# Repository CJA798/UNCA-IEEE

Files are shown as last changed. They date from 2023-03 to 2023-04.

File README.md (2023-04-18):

# UNCA-IEEE
### This repository contains all the latest code and CAD files for the bot
#### Important Links:
- [South East Con 2023 Hardware Competition](https://ieeesoutheastcon.org/)
- [Rules v3.0](https://ieeesoutheastcon.org/wp-content/uploads/sites/392/IEEE-SoutheastCon-2023-Hardware-Competition-Rules-v3.0.pdf)
- [Competition Schedule](https://ieeesoutheastcon.org/student-competitions/)

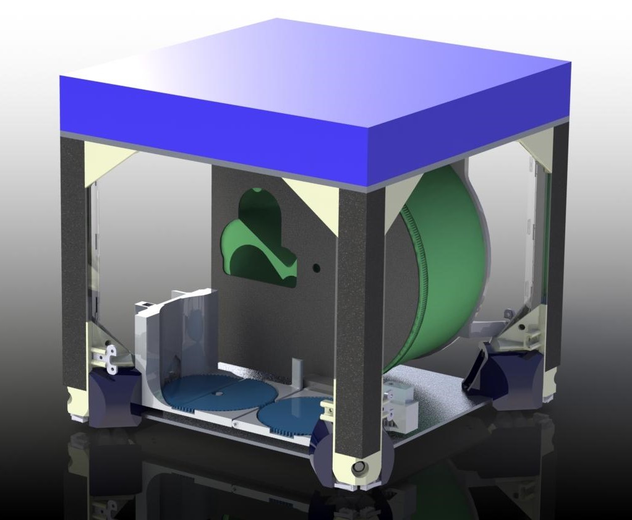
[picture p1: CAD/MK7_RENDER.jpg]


- <sub>[( ͡° ͜ʖ ͡°)](https://youtu.be/dQw4w9WgXcQ)</sub>

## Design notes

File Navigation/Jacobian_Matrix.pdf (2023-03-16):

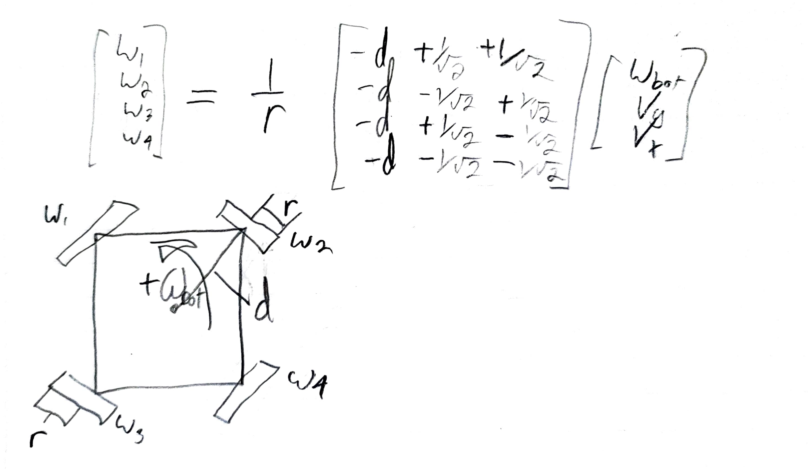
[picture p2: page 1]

-d t+
-V2 t
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
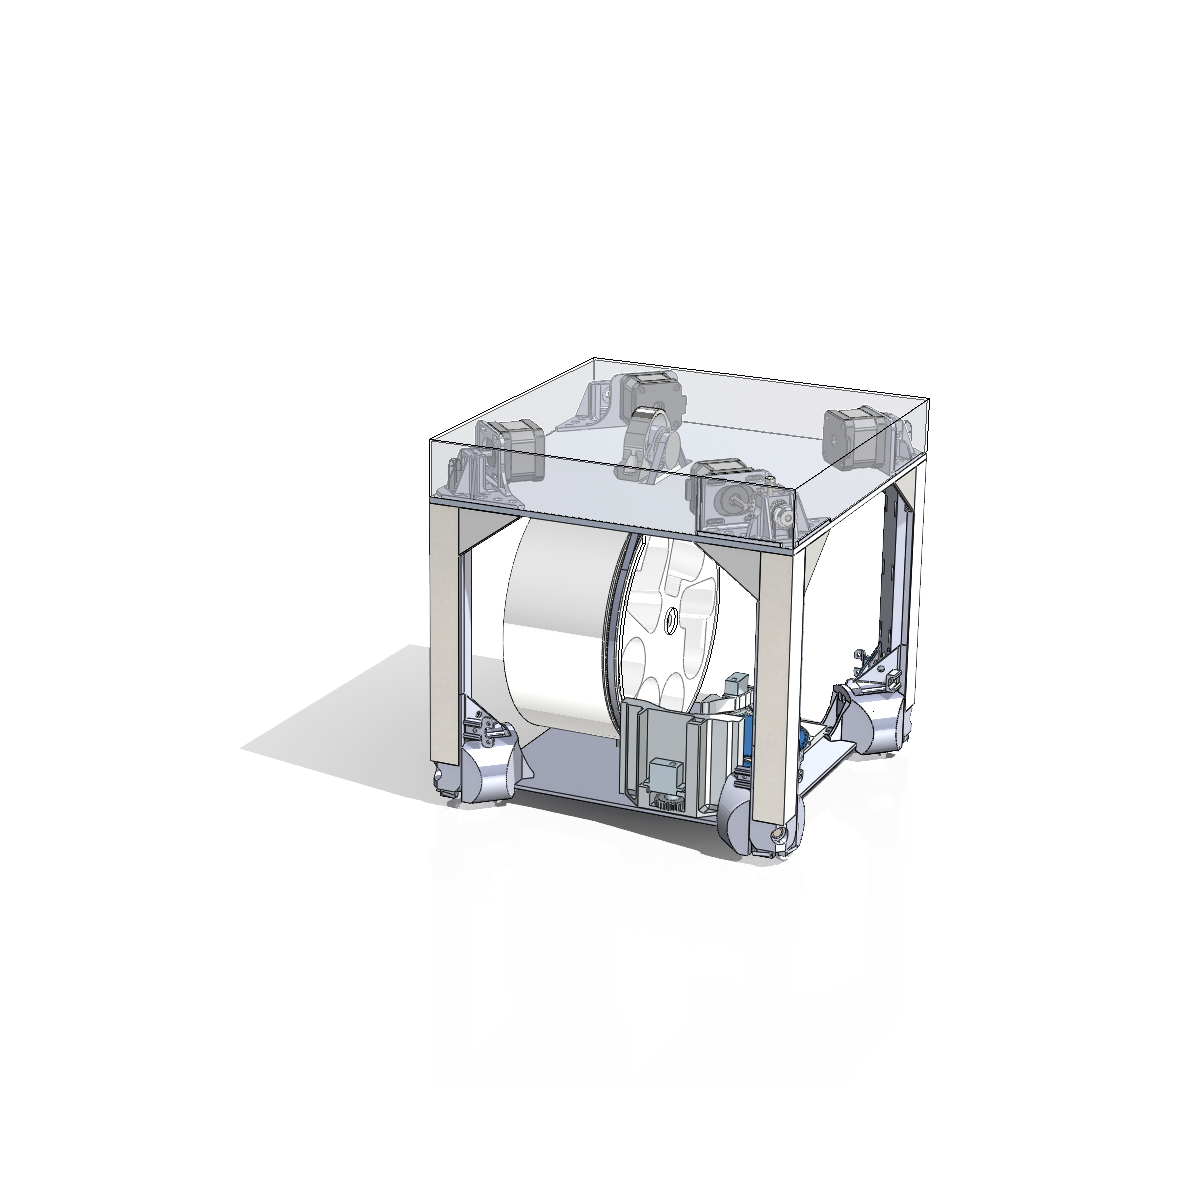
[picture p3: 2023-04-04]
CAD/MK5 IEEE BOT.PNG

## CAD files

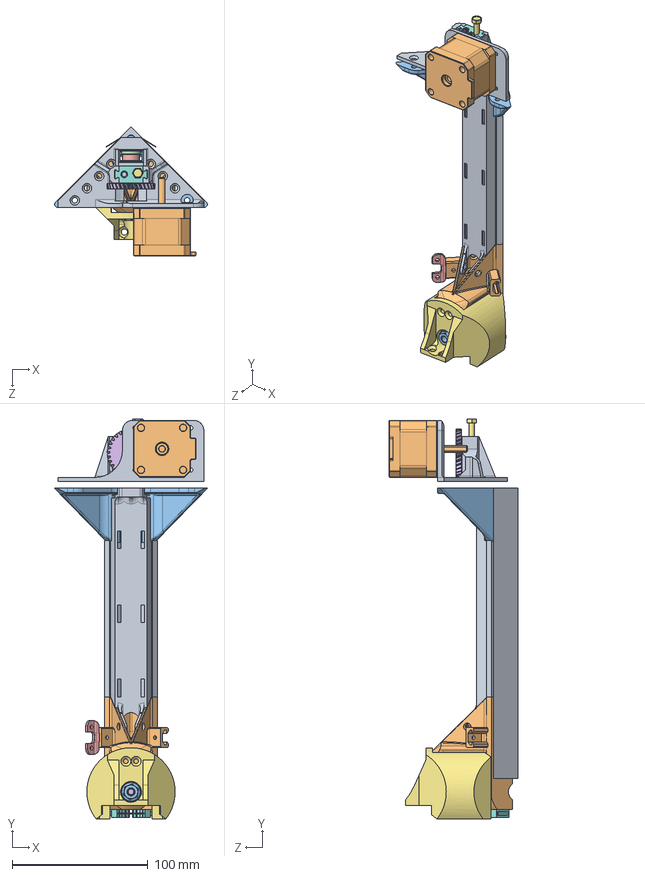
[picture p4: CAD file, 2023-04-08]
WORKING ASSEMBLY/MK7.1 IEEE BOT/LEG assem MK5.SLDASM
112.8 x 294.6 x 95.1 mm
Omniwheel Mount-MK5
Leg Bracket MK5
Omniwheel Hub
TOF sensor mount
Pinion Drive
Bottom Plate Bracket
Bearing Slider
Steel 90 degree MK5
Nema17.step
instrument ball bearing_68_am
6mm G2T Pully Gear
hex flange screw_am
Microswitch x 2
BeltShroud

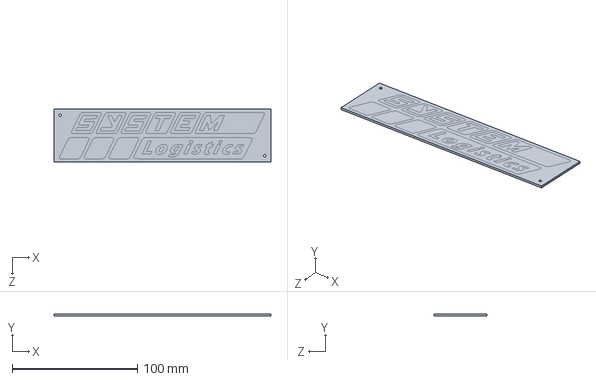
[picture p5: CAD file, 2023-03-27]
CAD/System Logistics Logo.SLDPRT
173.1 x 1.50 x 42.5 mm

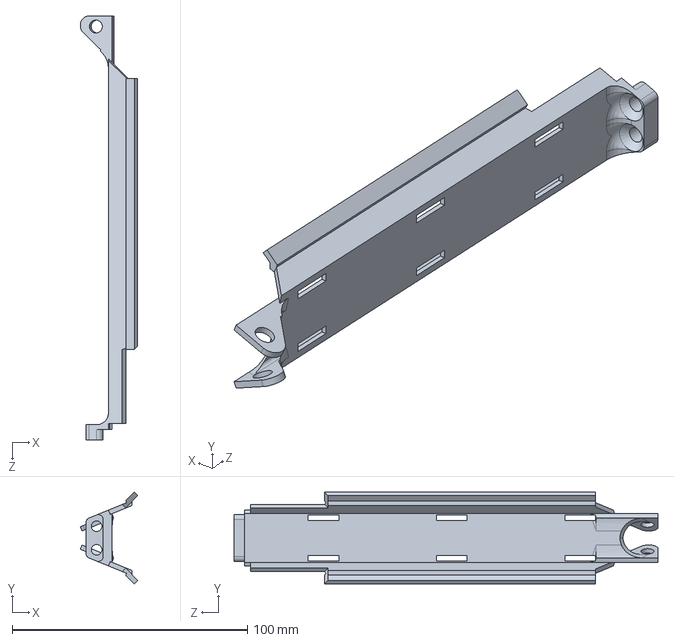
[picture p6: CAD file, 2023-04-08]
WORKING ASSEMBLY/MK7.1 IEEE BOT/BeltShroud.SLDPRT
24.4 x 39.0 x 180.1 mm

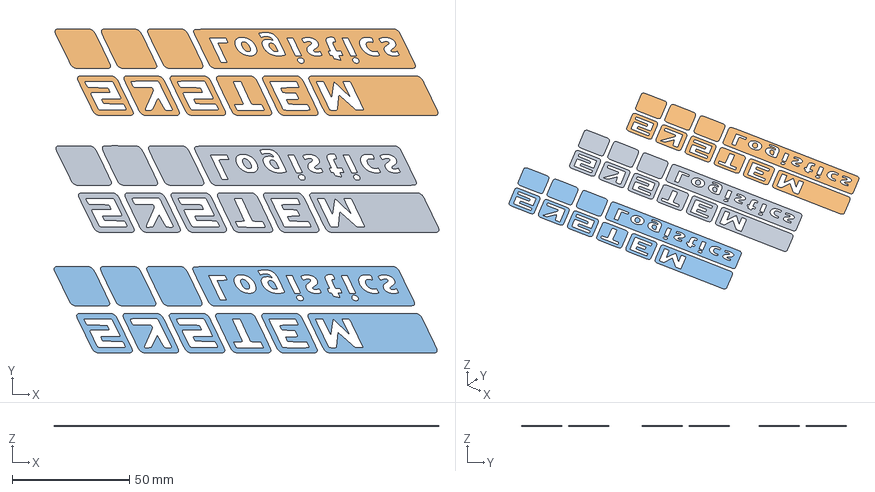
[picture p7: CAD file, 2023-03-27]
CAD/3 System Logistics Logos.3mf
164.3 x 138.4 x 0.18 mm
System Logistics Logo x 3

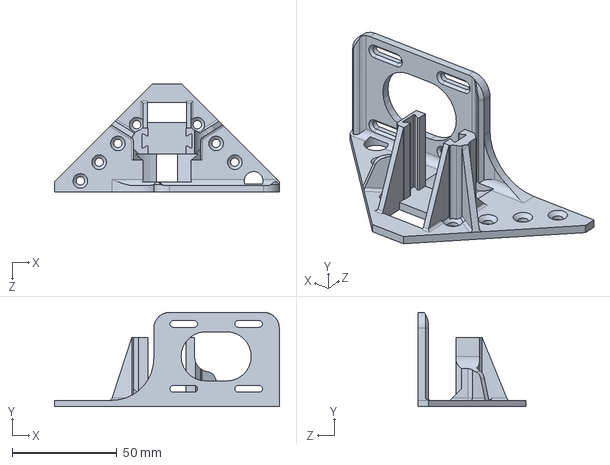
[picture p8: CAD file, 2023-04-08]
WORKING ASSEMBLY/MK7.1 IEEE BOT/Pinion Drive.SLDPRT
107.5 x 45.0 x 51.6 mm

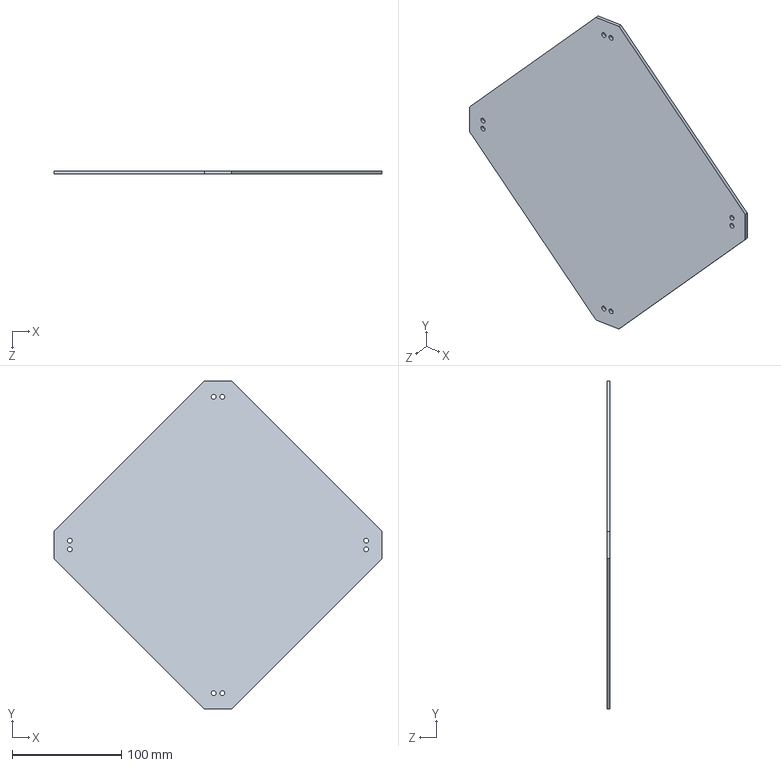
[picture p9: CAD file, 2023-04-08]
WORKING ASSEMBLY/MK7.1 IEEE BOT/Bottom Plate21.SLDPRT
300.7 x 300.7 x 3.00 mm

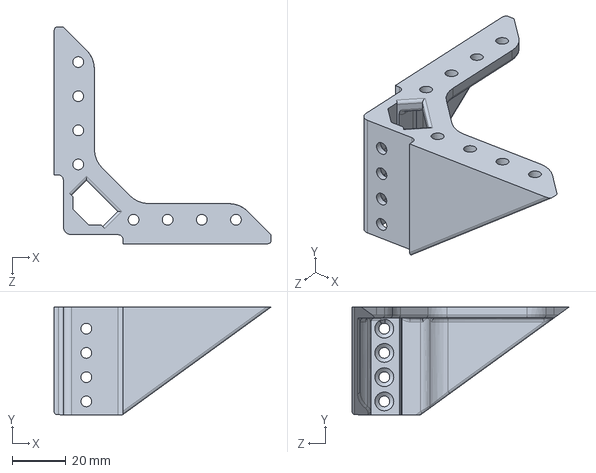
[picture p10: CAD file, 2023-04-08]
WORKING ASSEMBLY/MK7.1 IEEE BOT/Leg Bracket MK5.SLDPRT
80.5 x 40.0 x 80.5 mm

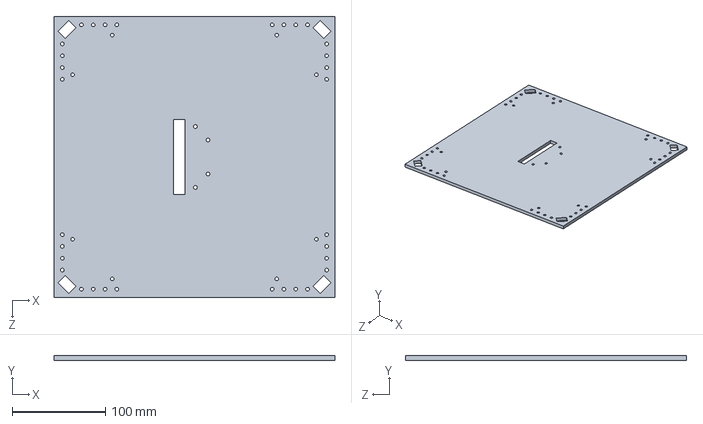
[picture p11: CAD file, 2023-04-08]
WORKING ASSEMBLY/MK7.1 IEEE BOT/MK5 Top Plate.SLDPRT
301.6 x 5.00 x 301.6 mm

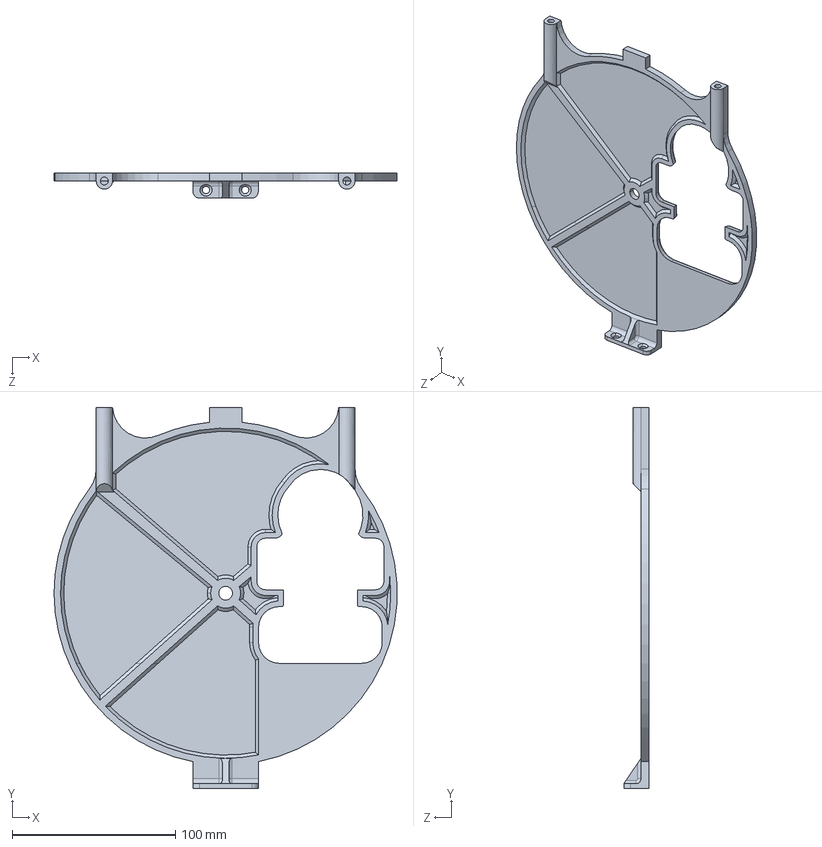
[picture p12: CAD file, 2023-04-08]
WORKING ASSEMBLY/MK7.1 IEEE BOT/DrumHolderBackPlate.step.SLDPRT
209.8 x 233.1 x 15.5 mm

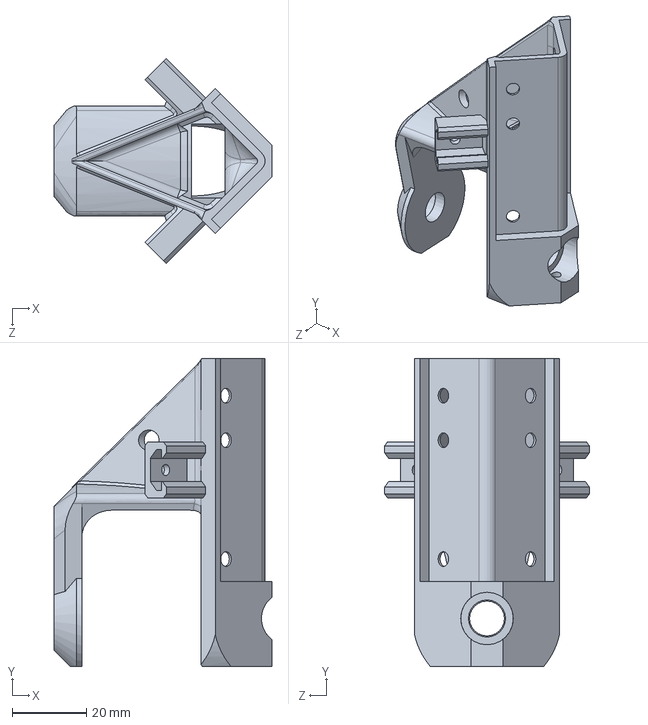
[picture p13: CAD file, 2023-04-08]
WORKING ASSEMBLY/MK7.1 IEEE BOT/Omniwheel Mount-MK5.SLDPRT
58.7 x 82.9 x 55.1 mm

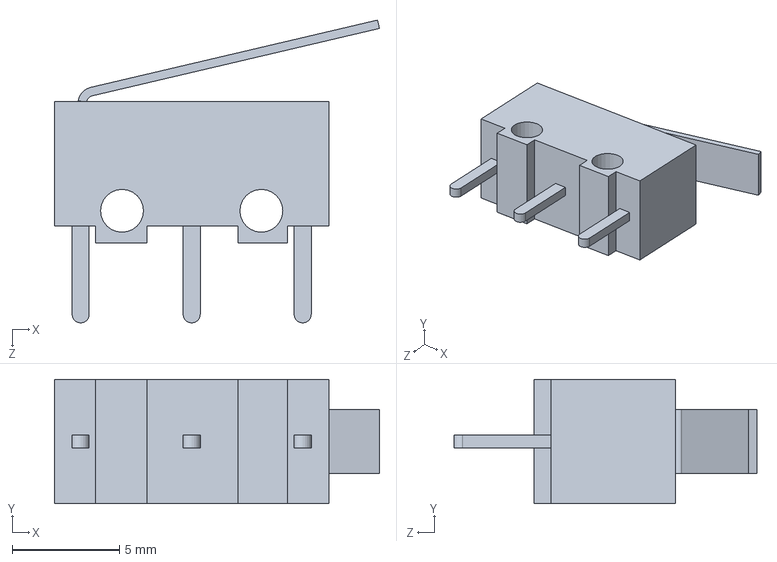
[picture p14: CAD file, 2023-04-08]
WORKING ASSEMBLY/MK7.1 IEEE BOT/Microswitch.SLDPRT
15.2 x 5.80 x 14.1 mm

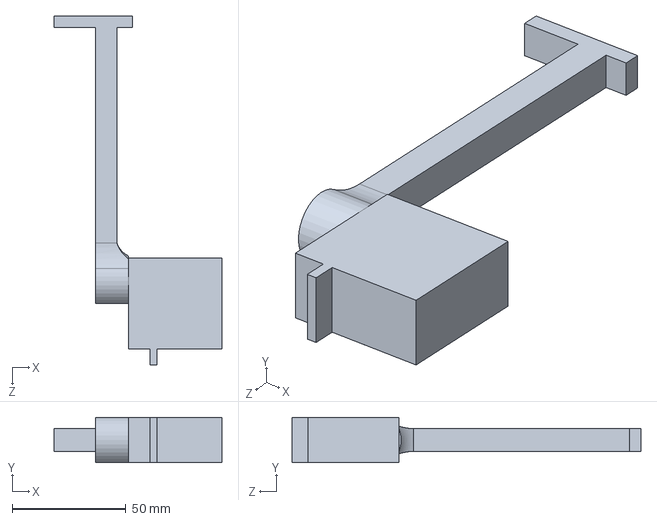
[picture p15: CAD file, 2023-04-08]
WORKING ASSEMBLY/MK7.1 IEEE BOT/DuckKicker.SLDPRT
73.7 x 20.0 x 153.6 mm

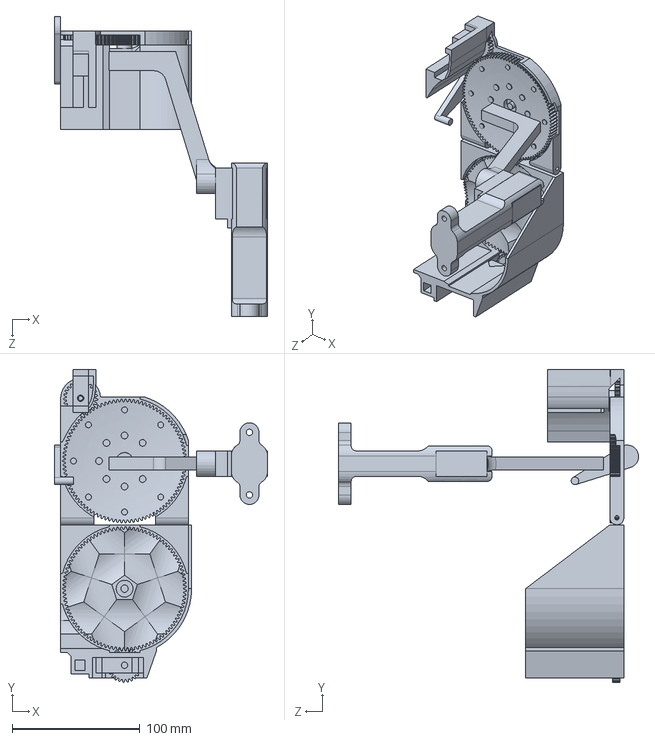
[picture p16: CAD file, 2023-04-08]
WORKING ASSEMBLY/MK7.1 IEEE BOT/FrontCollect.step.SLDPRT
167.0 x 245.1 x 235.1 mm

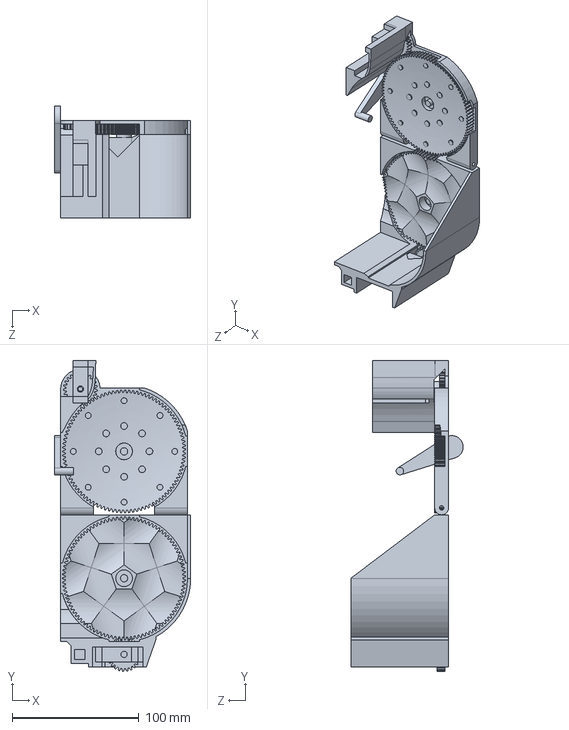
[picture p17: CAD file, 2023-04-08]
WORKING ASSEMBLY/MK7.1 IEEE BOT/RemovalDevice.SLDPRT
107.5 x 245.1 x 88.5 mm

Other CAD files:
WORKING ASSEMBLY/MK7.1 IEEE BOT/TopCover.SLDPRT
WORKING ASSEMBLY/MK7.1 IEEE BOT/Steel 90 degree MK5.SLDPRT
WORKING ASSEMBLY/MK7.1 IEEE BOT/Omniwheel Hub.SLDPRT
WORKING ASSEMBLY/MK7.1 IEEE BOT/twist_inside_plate.STEP
CAD/System Logistics Logo.3MF
CAD/System Logistics Logo.AMF
WORKING ASSEMBLY/MK7.1 IEEE BOT/2in 14mm omniwheel-MK5.SLDPRT
WORKING ASSEMBLY/MK7.1 IEEE BOT/3764N114_High-Strength Gt Timing Belt Pulley.SLDPRT
WORKING ASSEMBLY/MK7.1 IEEE BOT/6mm G2T Pully Gear.SLDPRT
WORKING ASSEMBLY/MK7.1 IEEE BOT/Bearing Slider.SLDPRT
WORKING ASSEMBLY/MK7.1 IEEE BOT/Belt.SLDPRT
WORKING ASSEMBLY/MK7.1 IEEE BOT/Bottom Plate Bracket.SLDPRT
WORKING ASSEMBLY/MK7.1 IEEE BOT/Nema14Pancake Stepper.SLDPRT
WORKING ASSEMBLY/MK7.1 IEEE BOT/TOF sensor mount.SLDPRT
WORKING ASSEMBLY/MK7.1 IEEE BOT/twist_inside_plate.SLDPRT

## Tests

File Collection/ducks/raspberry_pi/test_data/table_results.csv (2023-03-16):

label | left | top | right | bottom | score
cup | 63 | 199 | 205 | 376 | 0.66796875
dining table | -5 | 127 | 622 | 479 | 0.5859375
knife | 341 | 250 | 592 | 419 | 0.45703125
book | 94 | 127 | 402 | 219 | 0.43359375
refrigerator | 259 | 0 | 486 | 123 | 0.27734375

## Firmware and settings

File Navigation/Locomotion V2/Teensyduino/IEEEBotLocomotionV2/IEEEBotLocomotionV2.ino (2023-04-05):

#include <TeensyStep.h>
// #include <TeensyThreads.h>
#include <math.h>
// #include "Adafruit_VL53L1X.h"

#define IRQ_PIN1 2
#define XSHUT_PIN1 1

#define X_STEP 29 // A0 from mega
#define X_DIR 30  // A1 "   "
#define Y_EN 12   // A2
#define Y_STEP 9  // A6
#define Y_DIR 10  // A7
#define Z_STEP 7  // D46
#define Z_DIR 8   // D48
#define E0_DIR 6  // D28
#define E0_STEP 5 // D26
// Adafruit_VL53L1X TOF1 = Adafruit_VL53L1X(XSHUT_PIN1, IRQ_P
Stepper motor_1(29, 30); // Stepper objects
Stepper motor_2(9, 10);
Stepper motor_3(7, 8);
Stepper motor_4(5, 6);
StepControl controller; // Stepper controller object

#define mtx_type double            // Matrix type definition
#define ONE_OVR_RT_2 (0.707106)    // (1/sqrt(2))
#define STEPS_PER_ROTATION (3200)  // (200steps per rotation) * (16 microsteps per step)
#define STEPS_PER_CM (25.46)       // Steps per inch in arclength any given wheel travels = StepsPerWheelRotation/WheelCircumference
#define WHEEL_RADIUS (2.5)         // Radius of wheel(cm) (1in)
#define STEPS_PER_BOT_RAD (1) // = ((BotCircumference*StepsPerCm*)/(2*Pi))*3 (gear ratio)
#define STEPS_PER_DIST_MULT (27)   // = (1/sqrt(2))*StepsPerCM*3 (gear ratio)

// Stepper Settings
#define MAX_MTR_SPEED (7500) // Steps/s maximum is 300000
#define MAX_MTR_ACCEL (50)   // Steps/s^2 skips at around 15000

// GLOBALS

char KinematicsState;

mtx_type BotPose[3][1] = {
    {0},
    {0},
    {0}};
mtx_type InverseJacobian[4][3] = {
    {-STEPS_PER_BOT_RAD, STEPS_PER_DIST_MULT, STEPS_PER_DIST_MULT},
    {-STEPS_PER_BOT_RAD, STEPS_PER_DIST_MULT, -STEPS_PER_DIST_MULT},
    {-STEPS_PER_BOT_RAD, -STEPS_PER_DIST_MULT, STEPS_PER_DIST_MULT},
    {-STEPS_PER_BOT_RAD, -STEPS_PER_DIST_MULT, -STEPS_PER_DIST_MULT}};

// void TOFit(void)
//{
//   Wire.begin();
// TOF1.startRanging();
// vl53.setTimingBudget(15);
//}

void MatrixMultiply(mtx_type *A, mtx_type *B, int m, int p, int n, mtx_type *C)
{
    // A = input matrix (m x p)
    // B = input matrix (p x n)
    // m = number of rows in A
    // p = number of columns in A = number of rows in B
    // n = number of columns in B
    // C = output matrix = A*B (m x n)
    int i, j, k;
    for (i = 0; i < m; i++)
        for (j = 0; j < n; j++)
        {
            C[n * i + j] = 0;
            for (k = 0; k < p; k++)
                C[n * i + j] = C[n * i + j] + A[p * i + k] * B[n * k + j];
        }
}
void ComputeMoveAbs(mtx_type ThetaXY[3][1]) // Will not let you make a complex move (i.e. spinning while moving)Computes bots movement distances for each stepper motor using the bots inverse jacobian matrix
// and updates the stepper objects with this distance. The controller object must be updated for the steppers to start this move. ROTATIONAL MOVES ARE ALWAYS RELATIVE.
//  Input is in form [ Theta ]
//                   [    X  ]
//                   [    Y  ]
{
    // if ((ThetaXY[0][0] >= 0) && ((ThetaXY[1][0] >= 0) || (ThetaXY[2][0] >= 0)))
    //{
    // Return without doing anything if a complex input is detected.
    // return;
    Serial.println("ERROR: COMPLEX MOVE");
    //  }

    if (BotPose[0][0] > 0)
    { // if bot is skewed at an angle; calculate the actual desired movement vector. This is done by calculating the length of the vector, its angle, and then subtracting this angle from
        // the angle the bot is positioned at.
        double X = ThetaXY[1][0];
        double Y = ThetaXY[2][0];
        double R;
        double XYVectorAngle;
        if (X < 0)
        { // Quadrant 2
            R = sqrt((X * X) + (Y * Y));
            XYVectorAngle = atan(Y / X) + PI;
        }
        else if ((X < 0) && (Y < 0))
        { // Quadrant 3
            R = sqrt((X * X) + (Y * Y));
            XYVectorAngle = atan(Y / X) + PI;
        }
        else if (Y < 0)
        { // Quadrant 4
            R = sqrt((X * X) + (Y * Y));
            XYVectorAngle = atan(Y / X) + (2 * PI);
        }
        else
        { // Quadrant 1
            R = sqrt((X * X) + (Y * Y));
            XYVectorAngle = atan(Y / X);
        }
        X = R * cos(XYVectorAngle + BotPose[0][0]);
        Y = R * sin(XYVectorAngle + BotPose[0][0]);
        // ThetaXY[0][0] = 0;

        BotPose[0][0] += ThetaXY[0][0]; // Populate pose array
        BotPose[1][0] = ThetaXY[1][0];  // Populate pose array
        BotPose[2][0] = ThetaXY[2][0];  // Populate pose array

        ThetaXY[1][0] = X;
        ThetaXY[2][0] = Y;
    }
    else
    {

        BotPose[0][0] += ThetaXY[0][0]; // Populate pose array
        BotPose[1][0] = ThetaXY[1][0];  // Populate pose array
        BotPose[2][0] = ThetaXY[2][0];  // Populate pose array
    }
    Serial.println(ThetaXY[0][0]);
    Serial.println(ThetaXY[1][0]);
    Serial.println(ThetaXY[2][0]);

    mtx_type NewWheelSteps[4][1];

    MatrixMultiply((mtx_type *)InverseJacobian, (mtx_type *)ThetaXY, 4, 3, 1, (mtx_type *)NewWheelSteps); // Multiply our position array with the jacobian matrix to get distances for each wheel

    motor_1.setTargetRel(NewWheelSteps[0][0]); // update the stepper object
    motor_2.setTargetRel(NewWheelSteps[1][0]);
    motor_3.setTargetRel(NewWheelSteps[2][0]);
    motor_4.setTargetRel(NewWheelSteps[3][0]);
    // Serial.println(NewWheelSpeed[0][0]);
}

void ComputeMoveRel(mtx_type ThetaXY[3][1]) // Computes bots movement distances for each stepper motor using the bots inverse jacobian matrix
// and updates the stepper objects with this distance. The controller object must be updated for the steppers to start this move.
//  Input is in form [ Theta ]
//                   [    X  ]
//                   [    Y  ]
{
    mtx_type NewWheelSteps[4][1];

    MatrixMultiply((mtx_type *)InverseJacobian, (mtx_type *)ThetaXY, 4, 3, 1, (mtx_type *)NewWheelSteps); // Multiply our position array with the jacobian matrix to get distances for each wheel

    motor_1.setTargetRel(NewWheelSteps[0][0]); // update the stepper object
    motor_2.setTargetRel(NewWheelSteps[1][0]);
    motor_3.setTargetRel(NewWheelSteps[2][0]);
    motor_4.setTargetRel(NewWheelSteps[3][0]);
    // Serial.println(NewWheelSpeed[0][0]);
}
void InitSteppers(void)
{

    // setup the motors
    motor_1
        .setMaxSpeed(MAX_MTR_SPEED)      // steps/s
        .setAcceleration(MAX_MTR_ACCEL); // steps/s^2
    motor_2
        .setMaxSpeed(MAX_MTR_SPEED)      // steps/s
        .setAcceleration(MAX_MTR_ACCEL); // steps/s^2
    motor_3
        .setMaxSpeed(MAX_MTR_SPEED)      // steps/s
        .setAcceleration(MAX_MTR_ACCEL); // steps/s^2
    motor_4
        .setMaxSpeed(MAX_MTR_SPEED)      // steps/s
        .setAcceleration(MAX_MTR_ACCEL); // steps/s^2
}

// THREADS AND INTERRUPTS//////////////////////////////////////////////////////////////////
// void kinematics_compute_thread(void)
//{
// switch (kinematicsState)
// {
// }
//}

void setup()
{
    pinMode(0, INPUT); // Input for start button
    Serial.begin(9600);
    pinMode(13, OUTPUT);
    InitSteppers();
    // Serial.println("START");
    //  threads.addThread(kinematics_cqompute_thread);
}
int state = 0;
void loop()
{

    int buttonstate = digitalRead(0);
    Serial.println(buttonstate);
    if (buttonstate >= 1)
    {
        if (state == 1)
        {
            state = 0;
            digitalWrite(13, LOW);
        }
        else
        {
            state = 1;
            digitalWrite(13, HIGH);
        }
        delay(1000);
    }
    if (state == 1)
    {
        Serial.println("START");

        double Origin[3][1] = {{0}, {0}, {0}};
        double One[3][1] = {{0}, {0}, {25}};
        double Two[3][1] = {{0}, {25}, {0}};
        double Three[3][1] = {{0}, {25}, {25}};
        double Four[3][1] = {{0}, {-50}, {-50}};

        double SpinRt[3][1] = {{TWO_PI}, {0}, {0}};
        double SpinLft[3][1] = {{-TWO_PI}, {0}, {0}};

        double HalfSpinRt[3][1] = {{PI}, {0}, {0}};
        double HalfSpinLft[3][1] = {{-PI}, {0}, {0}};

        ComputeMoveAbs(Origin);
        // controller.move(motor_1, motor_2, motor_3, motor_4);
        // ComputeMoveAbs(One);
        // controller.move(motor_1, motor_2, motor_3, motor_4);
        // ComputeMoveAbs(Two);
        // controller.move(motor_1, motor_2, motor_3, motor_4);
        ComputeMoveAbs(Three);
        controller.move(motor_1, motor_2, motor_3, motor_4);
        ComputeMoveAbs(Four);
        controller.move(motor_1, motor_2, motor_3, motor_4);
        ComputeMoveAbs(HalfSpinRt);
        controller.move(motor_1, motor_2, motor_3, motor_4);
    }
}

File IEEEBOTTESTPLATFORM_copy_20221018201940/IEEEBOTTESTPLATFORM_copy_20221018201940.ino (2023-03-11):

/*
   Gamepad module provides three different mode namely Digital, JoyStick and Accerleometer.
   You can reduce the size of library compiled by enabling only those modules that you want to
   use. For this first define CUSTOM_SETTINGS followed by defining INCLUDE_modulename.
   Explore more on: https://thestempedia.com/docs/dabble/game-pad-module/
*/
#include <AccelStepper.h>
#include <MultiStepper.h>



#define CUSTOM_SETTINGS
#define INCLUDE_GAMEPAD_MODULE
#include <Dabble.h>
#define SDPOWER -1
//ChipSelect, Hardware SS Pin on Mega, 10 for Arduino Boards, always kept as output
#define SDCS_PIN 53
#define SD_DETECT_PIN -1  //currently not implemented
#define LED_PIN 13
#define FAN_PIN 9
#define PS_ON_PIN 12  //ATX , awake=LOW, SLEEP=High
#define KILL_PIN -1
#define HEATER_0_PIN 10  // Extruder Heater
#define HEATER_1_PIN 8
#define TEMP_0_PIN 13  // ANALOG NUMBERING
#define TEMP_1_PIN 14  // ANALOG NUMBERING
#define motorInterfaceType 1

/* Motor Definitions: Motors are labeled right to left looking at the board with the USB port at the top right;
i.e                                 arrangements on bot
  --------                    ============
  | A  B |                    |A        B|
  | C  D |                    |          |
  | E    |                    |          |
  --------                    |C        D|
                              ============
  (original schematic)

  --------
  | X  E0 |
  | Y  E1 |
  | Z     |
  --------
*/
// Function

void InitMotors(void);

// StateMachine
unsigned int StateMachineCount = 0;
bool OneTime = 0;
//const int BLUETOOTH_TX = 8;
//const int BLUETOOTH_RX = 7;
int incDist = 1;
int SpinSpeed = 400;
int Radius;
float angle;
bool onetime = 0;

// Motor Assignments

//SoftwareSerial bluetooth(BLUETOOTH_TX, BLUETOOTH_RX);
//ArduinoBlue phone(bluetooth); // pass reference of bluetooth object to ArduinoBlue constructor.

/*
void testSpin() {
  int pos1 = 500;
  int pos2 = 0;
  int testspeed = 200;
  int testpos = 400;
  if (GamePad.isStartPressed()) {
    onetime = 1;
  }
  if (GamePad.isSelectPressed()) {
    onetime = 0;
  }
  if (onetime) {

    // AStepper.setSpeed(testspeed);
    //DStepper.setSpeed(testspeed);
    //CStepper.setSpeed(testspeed);
    //BStepper.setSpeed(testspeed);
    if (AStepper.distanceToGo() == 0) {
      digitalWrite(LED_BUILTIN, HIGH);
      AStepper.moveTo(-AStepper.currentPosition());
      BStepper.moveTo(-BStepper.currentPosition());
      CStepper.moveTo(-CStepper.currentPosition());
      DStepper.moveTo(-DStepper.currentPosition());
    }

    AStepper.run();
    BStepper.run();
    CStepper.run();
    DStepper.run();
  }
}
void testMotors() {
  CStepper.setSpeed(200);
  CStepper.move(10);
  CStepper.run();
}


*/
void setup() {
  // put your setup code here, to run once:

  pinMode(LED_BUILTIN, OUTPUT);
  InitMotors();

  Serial.begin(230400);  // make sure your Serial Monitor is also set at this baud rate.
  Dabble.begin(9600);    //Enter baudrate of your bluetooth.Connect bluetooth on Bluetooth port present on evive.
  digitalWrite(LED_BUILTIN, LOW);

  //testMotors();
}

void loop() {
 // if (StateMachineCount >= 10) {
 //   StateMachineCount = 0;
    Dabble.processInput();  //this function is used to refresh data obtained from smartphone.Hence calling this function is mandatory in order to get data properly from your mobile.
 // }
  angle = GamePad.getAngle();
  Radius = GamePad.getRadius();
  Radius = map(Radius, 0, 7, 0, 400);
  angle = (angle * PI) / 180;
  digitalWrite(LED_BUILTIN, LOW);

  // m,testSpin();
  if (Radius >=1) {
    digitalWrite(LED_BUILTIN, HIGH);
  }
  move();
}

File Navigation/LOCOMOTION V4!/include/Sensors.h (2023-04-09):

#include <macros.h>
#include <Bounce2.h>
#include <math.h>
#include "Adafruit_VL53L1X.h"
#include "Adafruit_VL53L0X.h"
#include <ports.h>
// #include <Adafruit_I2CDevice.h>
// #include <Adafruit_Sensor.h>
// #include <Wire.h>
#define X_MAX (122)
#define Y_MAX (122)
#define X_MIN (-122)
#define Y_MIN (0)
#define FRONT_PRESSED (0)
#define RIGHT_PRESSED (1)
#define BACK_PRESSED (2)
#define LEFT_PRESSED (3)
#define NONE_PRESSED (4)
/* The Libraries for the magnetometer/gyroscope cause errors.

#include <Adafruit_SPIDevice.h>

#include <Adafruit_BNO055.h>
*/
Bounce FrontLeftSw;
Bounce FrontRightSw;
Bounce BackRightSw;
Bounce BackLeftSw;
Bounce RightSideRightSw;
Bounce RightSideLeftSw;
Bounce LeftSideRightSw;
Bounce LeftSideLeftSw;

char SwitchesState = 4;
bool ChangeInSwitchState = 0;
double SwitchAngle = 0;
class BumperSwitches
{ // This class will contain the functions to read the construct the bumpers switches, read from the switches, and set flags for when the X_min, X_max, Y_min, Y_max bounds are reached.

private:
public:
  BumperSwitches()
  {
    FrontLeftSw = Bounce();
    FrontRightSw = Bounce();
    BackRightSw = Bounce();
    BackLeftSw = Bounce();
    RightSideRightSw = Bounce();
    RightSideLeftSw = Bounce();
    LeftSideRightSw = Bounce();
    LeftSideLeftSw = Bounce();
 
    pinMode(FRONT_LEFT_SWITCH, INPUT_PULLUP);
    pinMode(FRONT_RIGHT_SWITCH, INPUT_PULLUP);
    pinMode(RIGHTSIDE_LEFT_SWITCH, INPUT_PULLUP);
    pinMode(RIGHTSIDE_RIGHT_SWITCH, INPUT_PULLUP);
    pinMode(LEFTSIDE_LEFT_SWITCH, INPUT_PULLUP);
    pinMode(LEFTSIDE_RIGHT_SWITCH, INPUT_PULLUP);
    pinMode(RIGHTSIDE_RIGHT_SWITCH, INPUT_PULLUP);
    pinMode(BACK_RIGHT_SWITCH, INPUT_PULLUP);
    pinMode(BACK_LEFT_SWTICH, INPUT_PULLUP);


    FrontRightSw.attach(FRONT_RIGHT_SWITCH); // 1
    FrontRightSw.interval(DEBOUNCE_TIME);
    FrontLeftSw.attach(FRONT_LEFT_SWITCH); // 2
    FrontLeftSw.interval(DEBOUNCE_TIME);
    BackRightSw.attach(BACK_RIGHT_SWITCH); // 3
    BackRightSw.interval(DEBOUNCE_TIME);
    BackLeftSw.attach(BACK_LEFT_SWTICH); // 3
    BackLeftSw.interval(DEBOUNCE_TIME);
    RightSideRightSw.attach(RIGHTSIDE_RIGHT_SWITCH); // 4
    RightSideRightSw.interval(DEBOUNCE_TIME);
    RightSideLeftSw.attach(RIGHTSIDE_LEFT_SWITCH); // 5
    RightSideLeftSw.interval(DEBOUNCE_TIME);
    LeftSideRightSw.attach(LEFTSIDE_RIGHT_SWITCH); // 6
    LeftSideRightSw.interval(DEBOUNCE_TIME);
    LeftSideLeftSw.attach(LEFTSIDE_LEFT_SWITCH); // 6
    LeftSideLeftSw.interval(DEBOUNCE_TIME);
  }

  void SwitchesProcess(void)
  {
    // Serial.println("SwitchesProcess");
    FrontRightSw.update();     // 1
    FrontLeftSw.update();      // 2
    BackLeftSw.update();       // 3
    BackRightSw.update();      // 4
    RightSideLeftSw.update();  // 5
    RightSideRightSw.update(); // 6
    LeftSideLeftSw.update();   // 7
    LeftSideRightSw.update();  // 8
    SwitchesState = NONE_PRESSED;
    if (!(FrontLeftSw.read() && FrontRightSw.read()))
    {

      SwitchesState = FRONT_PRESSED;
    }
    else if (!(BackLeftSw.read() && BackRightSw.read()))
    {

      SwitchesState = BACK_PRESSED;
    }
    else if (!(RightSideLeftSw.read() && RightSideRightSw.read()))
    {

      SwitchesState = RIGHT_PRESSED;
    }
    else if (!(LeftSideLeftSw.read() && LeftSideRightSw.read()))
    {

      SwitchesState = LEFT_PRESSED;
    };
  };
  void PrintPosition()
  {
    Serial.println("SwitchesState: ");
    Serial.println(" ");
    Serial.print("FrontRightSw: ");
    Serial.println(FrontRightSw.read());
    Serial.print("FrontLeftSw: ");
    Serial.println(FrontLeftSw.read());
    Serial.print("BackLeftSw: ");
    Serial.println(BackLeftSw.read());
    Serial.print("BackRightSw: ");
    Serial.println(BackRightSw.read());
    Serial.print("RightSideLeftSw: ");
    Serial.println(RightSideLeftSw.read());
    Serial.print("RightSideRightSw: ");
    Serial.println(RightSideRightSw.read());
    Serial.print("LeftSideLeftSw: ");
    Serial.println(LeftSideLeftSw.read());
    Serial.print("LeftSideRightSw: ");
    Serial.println(LeftSideRightSw.read());
  }
};

class TOFArray
{
private:
  struct TOFData_mm
  {
    uint16_t FrontBigTOFMeasurementmm = 0;
    uint16_t BackTOFMeasurementmm = 0;
    uint16_t RightTOFMeasurementmm = 0;
    uint16_t LeftTOFMeasurementmm = 0;
    VL53L0X_RangingMeasurementData_t FrontSmallTOFMeasurementmm;
    VL53L0X_RangingMeasurementData_t BackSmallTOFMeasurementmm;
    VL53L0X_RangingMeasurementData_t RightSmallTOFMeasurementmm;
    VL53L0X_RangingMeasurementData_t LeftSmallTOFMeasurementmm;
  };
  Adafruit_VL53L1X BigTOF_Front;
  Adafruit_VL53L1X BigTOF_Back;
  Adafruit_VL53L1X BigTOF_Right;
  Adafruit_VL53L1X BigTOF_Left;
  Adafruit_VL53L0X SmallTOF_Front;
  Adafruit_VL53L0X SmallTOF_Back;
  Adafruit_VL53L0X SmallTOF_Right;
  Adafruit_VL53L0X SmallTOF_Left;
  TOFData_mm TOFData;
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

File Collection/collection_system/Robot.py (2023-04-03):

from FlipperPlatform import FlipperPlatform, FlipperPlatformStatus
from Drum import Drum, DrumStatus
from ElevatorPlatform import Elevator, ElevatorStatus
from Pusher import Pusher, PusherStatus
from BraceCode import BRACE_ACTION
#from Brace import BraceStuff. Needs to be added when Maxwell pushes


class RobotStatus:
    WAITING = 0
    COLLECT = 1
    
class Robot:
    def __init__(self):
        self.CollectionSystem = CollectionSystem()
        self.NavigationSystem = None
    
class CollectionSystem:
    def __init__(self):
        self.Flipper = FlipperPlatform()
        self.Drum = Drum()
        self.Elevator = Elevator()
        self.Pushers = Pusher()
        self.Brace = BRACE_ACTION()
        #Brace stuff
        

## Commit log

2022-10-20 stepper motors code with bluetooth added
2022-12-15 Working object detection and orientation
    [pyvenv.cfg]
2022-12-15 simplified folder
    [pyvenv.cfg, table_results.csv]
2022-12-28 DC motor keyboard control
    DC motor car controlled by keyboard through VNC. Hardware: Raspberry Pi 3B+, Adafruit stepper & DC motor shield, and Adafruit ISM330DLC IMU.
2023-01-05 Kalman Filter Included
    Made new robot class that includes the sensors, shields, and KF.
2023-02-13 New files for camera module v3, taking pictures, detection using picamera2, good trained models
2023-02-27 DataPackage class seems to work.
    NEED CIRCUIT TESTING
2023-02-28 Added LEDs and servo to test program
2023-03-02 LEDs and servo work. Needs RPi test.
2023-03-03 Create MK5.5 IEEE BOT.zip
    Added Bottom Plate
2023-03-16 Added systems logistic logo
    [System Logistics Logo.SLDPRT]
2023-03-17 fixed area size and added prints for detection list
    [communication_test.py]
2023-03-17 fixed class index and now index is printed
    [communication_test.ino, communication_test.py, macros.h]
2023-03-17 single hard-coded class works. LEDs too slow
    [communication_test.py]
2023-03-17 fixed deleted stuff. this is the real pre-re-structure file
    [communication_test.py]
2023-03-17 fixed contour error. now contours don't show up
    [communication_test.py]
2023-03-17 fixed contours not showing up. Need to fix excessive contours showing up
    [communication_test.py]
2023-03-17 added safe arduino exit on keyboard interrupt
2023-03-17 test single image filtered contours
2023-03-17 simplified utils.py, fixed contours offset, white contours not displaying properly
    [communication_test.py, utils.py]
2023-03-17 contours and color problems fixed. This is a good checkpoint
    [communication_test.py]
2023-03-18 first attempt to send index and angle. somewhere theres a list index out of range error
    [communication_test.py]
2023-03-18 Fixed buffer error. This is a good checkpoint
    [communication_test.py]
2023-03-18 Buffer fix Arduino code
    [communication_test.ino]
2023-03-20 arduino baud change
2023-03-20 Added TOF Sensor test code and matlab code
2023-03-21 Added the most recent CAD assembly (mk5.7)
2023-03-23 added RESTART signal for teensy
2023-03-23 RESET signal seems to work
    [communication_test.py]
2023-03-24 Revert "RESET signal seems to work"
    This reverts commit 273b6e17642e5050aa0e2b28b53e49ffcf0d22ff.
    [communication_test.py]
2023-03-24 RESET seems to work v2
    [communication_test.ino]
2023-03-26 Updated Systems Logistics Logo
    [3 System Logistics Logos.3mf, System Logistics Logo.3MF, System Logistics Logo.AMF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]
2023-03-28 Fixed little errors and syntax. Added elevator and tower builder classes
    [FlipperPlatform.h, macros.h]
2023-03-28 NEED TEENSY 3.X. Fixed compiling errors and added useful comments
    [FlipperPlatform.h, communication_test.ino, macros.h]
2023-03-29 Added working limit switches
2023-03-29 added newest CAD
    added belt shrouds, a top cover, and ivans early version of the flipper mechanism
2023-03-29 update to stepper motor distance counts
2023-03-30 Replaced nasty functions and spaghetti code with object oriented code
    [macros.h, main.cpp]
2023-03-30 FIXED: hat stopped working next day -> added restart to the hat to solve it
    [collection.py, test.py]
2023-03-30 flipper works. need to fix async-while issue
    [FlipperPlatform.py, collection.py]
2023-03-31 modified frame size and flipper servo range
    [FlipperPlatform.py, modular.py, test.py]
2023-04-02 Backup
    Lots of code from me trying to get asycronous motors running; but there is a bug where the teensystep library stops driving the motors after a few moves.
    [Sensors.h, main.cpp]
2023-04-02 detection print test
2023-04-02 Got my global movements to work in the serial.prints; but somehow the correct speed does not get written to the steppers.
    [macros.h, main.cpp]
2023-04-02 TODO: fix contour error. Cylinders not contoured
    [CameraSystem.py, test.py, utils.py]
2023-04-04 Revert "Delete CAD directory"
    This reverts commit f5ee14a990541654b2b1d3f647a3c0f819eca601.
    [3 System Logistics Logos.3mf, System Logistics Logo.3MF, System Logistics Logo.AMF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]
2023-04-06 Added complex move function; but the motors are not updating their speeds properly.
2023-04-08 Updating Cad
    [2in 14mm omniwheel-MK5.SLDPRT, 3764N114_High-Strength Gt Timing Belt Pulley.SLDPRT, 6mm G2T Pully Gear.SLDPRT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]
2023-04-09 Added bumper positional reset functions
    [Drum.h, Sensors.h, macros.h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]
2023-04-09 Drum is not asycronous, serial is broke
    [main.cpp]
